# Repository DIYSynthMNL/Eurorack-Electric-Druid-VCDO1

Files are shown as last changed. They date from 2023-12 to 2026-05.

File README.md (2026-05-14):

This module is shared under a [Creative Commons Attribution-NonCommercial-ShareAlike 4.0 International license](https://creativecommons.org/licenses/by-nc-sa/4.0/). All credits go to Tom Wiltshire, founder of Electric Druid.

# Eurorack Electric Druid VCDO1

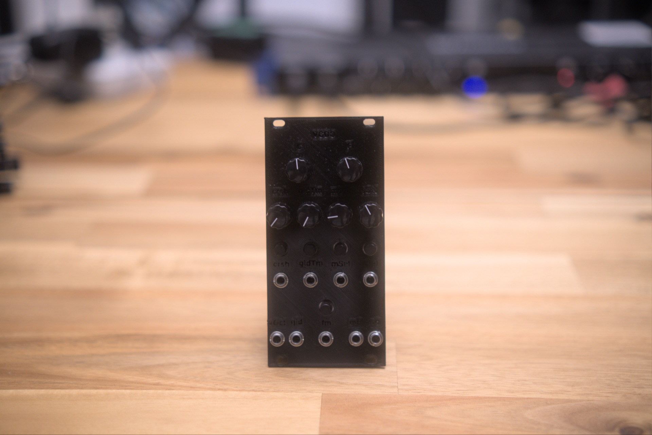
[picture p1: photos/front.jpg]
Electric Druid VCDO1 assembled


A Eurorack wavetable oscillator module built around the [VCDO1](https://electricdruid.net/product/vcdo-wavetable-oscillator/) chip from Electric Druid. The VCDO1 is a digital wavetable + sub-oscillator chip in an 18-pin DIP, running its own DAC internally and exposing both main and sub waveform outputs.

## Features

- **16 main waveforms** with smooth morphing via the Wave Select control
- **8 sub waveforms** with 4 selectable octave offsets (+1 oct, unison, −1 oct, −2 oct)
- **V/oct Note CV** input (0–5V, 5 octaves) with V/oct gain trim and offset trim
- **Exponential FM CV** input (±5V) with zero trim
- **Wave Select CV** for main and sub waveforms (±5V each)
- **Bitcrush** amount with both panel control and CV input
- **Glide (portamento)** time with both panel control and CV input, plus a separate Glide on/off gate input
- Two simultaneous outputs: Main oscillator and Sub oscillator (10Vpp each, anti-aliased)
- Eurorack ±12V power via either 16-pin IDC or 3-pin JST connector

The module adds **CV-controllable bitcrush and glide amounts** on top of the original Electric Druid VCDO datasheet circuit.

## Inputs and outputs

| Jack | Range | Notes |
|---|---|---|
| Note CV | 0–5V | 1V/oct, scaled to chip's 0–5V range; trim pots adjust V/oct and offset |
| FM CV | ±5V (10Vpp) | Inverted, scaled, offset-shifted to 0–5V; zero trim |
| Main Wave Select CV | ±5V (10Vpp) | Inverted, scaled, offset-shifted to 0–5V |
| Sub Wave Select CV | ±5V (10Vpp) | Inverted, scaled, offset-shifted to 0–5V |
| Bitcrush CV | ±5V (10Vpp) | Mixed with front-panel Bitcrush Control via Amount attenuator |
| Glide Time CV | ±5V (10Vpp) | Mixed with front-panel Glide Time Control via Amount attenuator |
| Glide on/off CV | 0–5V (gate) | NPN-buffered, drives chip's digital glide input |
| Main Out | 10Vpp | 4-pole Bessel reconstruction filter (≈18 kHz), buffered, 1K series |
| Sub Out | 10Vpp | Identical filter chain |

## Block diagram

```
                                  ┌───────────────────┐
  Note CV ─► [V/oct + offset] ──► │                   │
   FM CV ─► [scale + zero] ─────► │                   │ Main ─► [4-pole Bessel LP] ─► Main Out
  MainSel ─► [scale + offset] ──► │                   │
  SubSel ─► [scale + offset] ───► │   VCDO1 chip      │
 Bitcrush ─► [pot + CV+amount] ─► │   (digital        │
GlideTime ─► [pot + CV+amount] ─► │    wavetable      │
Glide on/off ─► [NPN inverter] ─► │    oscillator)    │ Sub  ─► [4-pole Bessel LP] ─► Sub Out
                                  │                   │
  Pots (Course, Fine,             │                   │
   MainSel, SubSel) ────────────► │                   │
                                  └───────────────────┘

  Eurorack ±12V ─► U6 (78M05) / U7 (79M05) ─► ±5V rails
```

## Power

- Eurorack ±12V in via **J3** (3-pin JST) or **J4** (16-pin IDC) — populate one
- Local U6 (78M05) generates +5V from +12V
- Local U7 (79M05) generates −5V from −12V
- R45 / R46 (10K) are optional minimum-load resistors

> **Note on the Electric Druid datasheet:** The original VCDO1 datasheet circuit has an error in the negative 5V regulator wiring. This schematic corrects it — verify when copying from the datasheet directly.

## Calibration

The board has three trim pots that need adjustment for accurate tracking. You'll need: a multimeter, a calibrated reference tone source (a tuner app, another tuned VCO, or a 1V/oct keyboard).

**RV1 — V/oct Adjust** sets the per-octave gain of the Note CV.
**RV2 — Offset trim** sets the DC offset of the Note CV (the "zero" pitch when 0V is applied).
**RV3 — FM Zero trim** ensures no DC drift on the FM input when nothing is patched.

Procedure:

1. **Warm up.** Power the module for at least 5 minutes — the temperature affects the chip and trim accuracy.
2. **Set baseline.** Freq Course and Fine at 12 o'clock. Nothing patched.
3. **Tune the base pitch.** Apply 0V to the Note CV jack (or short the jack tip to GND). Adjust **RV2 (Offset trim)** until the main output matches a known low reference (e.g., C2 = 65.41 Hz).
4. **Tune the per-octave gain.** Apply +4V to the Note CV jack. Adjust **RV1 (V/oct)** until the main output is exactly 4 octaves higher than step 3 (e.g., C6 = 1046.5 Hz).
5. **Iterate.** Step 3–4 interact slightly; bounce between them until both are accurate.
6. **Zero the FM input.** With Note CV at 0V and nothing patched into FM, adjust **RV3 (FM Zero trim)** until probing AIN_Freq_Mod_CV (or the FM jack tip) shows ~0V DC.

If tracking drifts at the extremes (very low or very high notes), check the timing capacitor area on the VCDO1 (this is a chip-internal characteristic).

## References

Local archived copies live in [`references/`](references/) so this repo stays useful if the upstream links die.

- **VCDO1 datasheet (Tom Wiltshire / Electric Druid, 2015)** — [local copy](references/VCDO1-Datasheet-ElectricDruid-2015.pdf) · [upstream](https://electricdruid.net/wp-content/uploads/2015/07/VCDO-Datasheet.pdf) — chip pinout, example circuit, and waveform reference. Note the negative-5V-regulator wiring error called out above; this schematic corrects it.
- [Electric Druid VCDO1 product page](https://electricdruid.net/product/vcdo-wavetable-oscillator/)

## Build status

What's ready for builders today, and what's still on the TODO list:

**Production assets** (what you need to actually fabricate and assemble a final unit)

- [x] Schematic — Rev 0.1.5 ([PDF](Schematic%20PDFs/Electric%20Druid%20VCDO1_Multiboard_Schematic_0.1.5.pdf))
- [ ] PCB layout — in progress — multiboard layout in `kicad/`, not yet separated for fab
- [ ] Gerber files for fabrication — none yet
- [x] BOM — [BOMs - VCDO1 - Schematic Rev 0.1.2.pdf](BOMs/BOMs%20-%20VCDO1%20-%20Schematic%20Rev%200.1.2.pdf)
- [ ] Final front panel (SVG/PDF for fab) — none yet
- [x] License — [LICENSE](LICENSE)

**Prototype assets** (for breadboard / perfboard / 3D-printed-panel builds before final PCB)

- [x] 3D-printed prototype panel STL — [VCDO.stl](3D%20printed%20front%20panel/VCDO.stl)

**Documentation**

- [x] Photos of the assembled module — see [photos/](photos/)
- [ ] Demo video — none yet
- [ ] Build / assembly instructions — none yet

Want to help fill a gap (build photos, gerbers, an assembly guide)? Open an issue or PR.

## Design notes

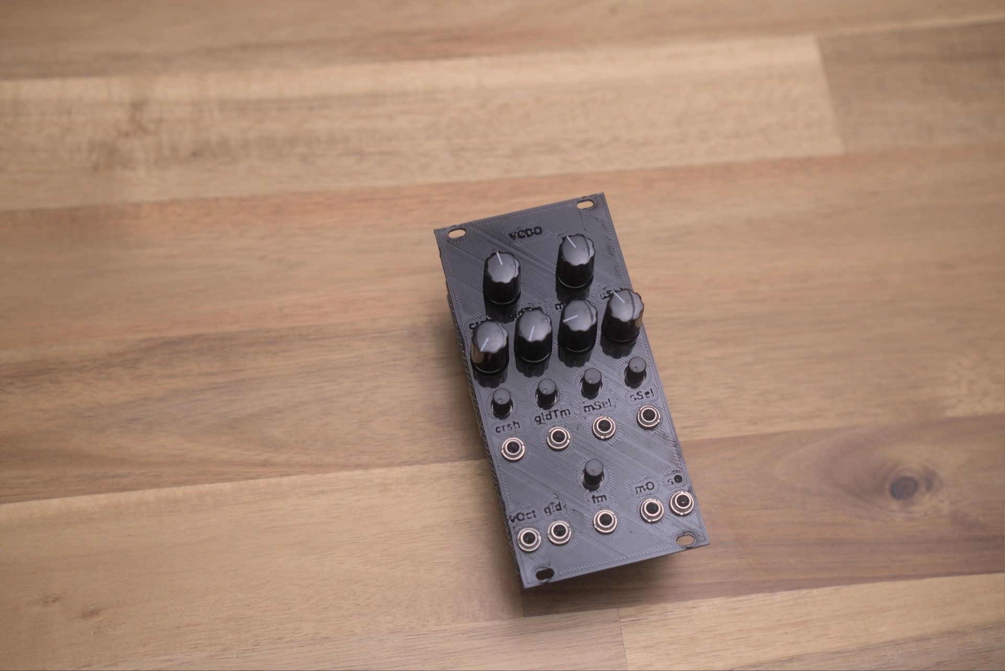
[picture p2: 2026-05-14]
photos/front-angle.jpg

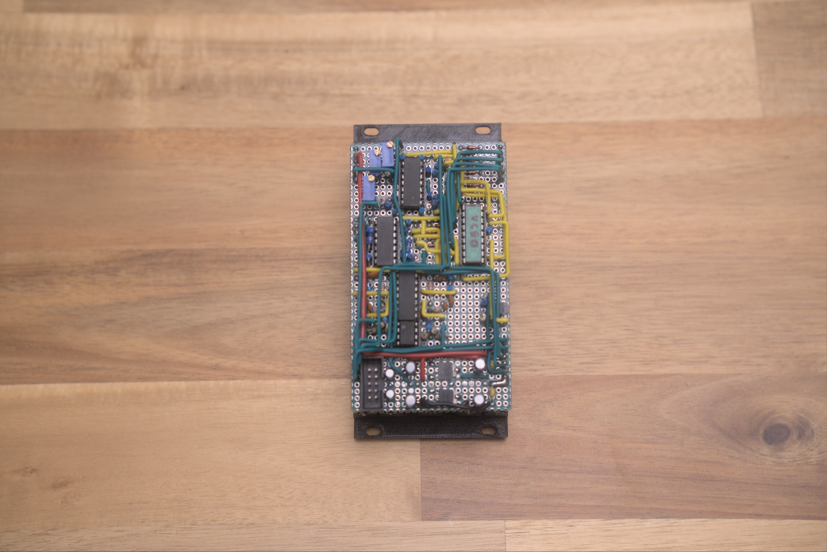
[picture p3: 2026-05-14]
photos/prototype-board-back.jpg

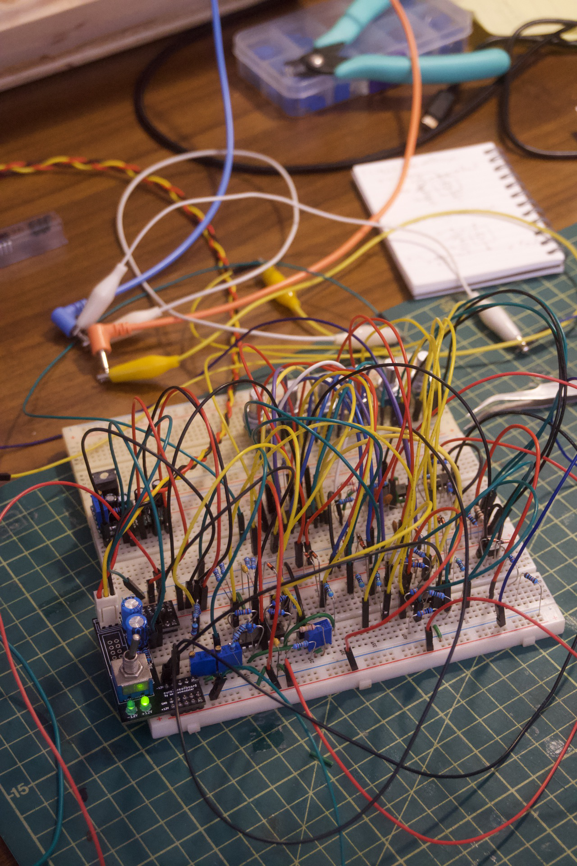
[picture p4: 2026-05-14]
photos/breadboarding/breadboard-2.jpg

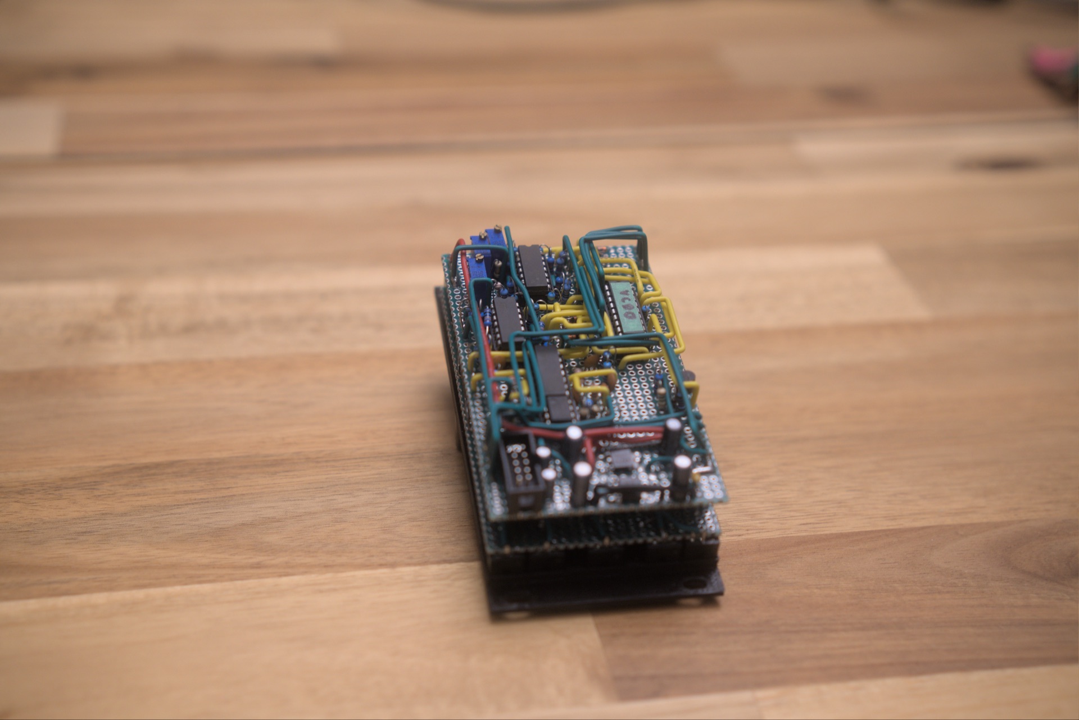
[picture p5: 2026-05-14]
photos/prototype-board.jpg

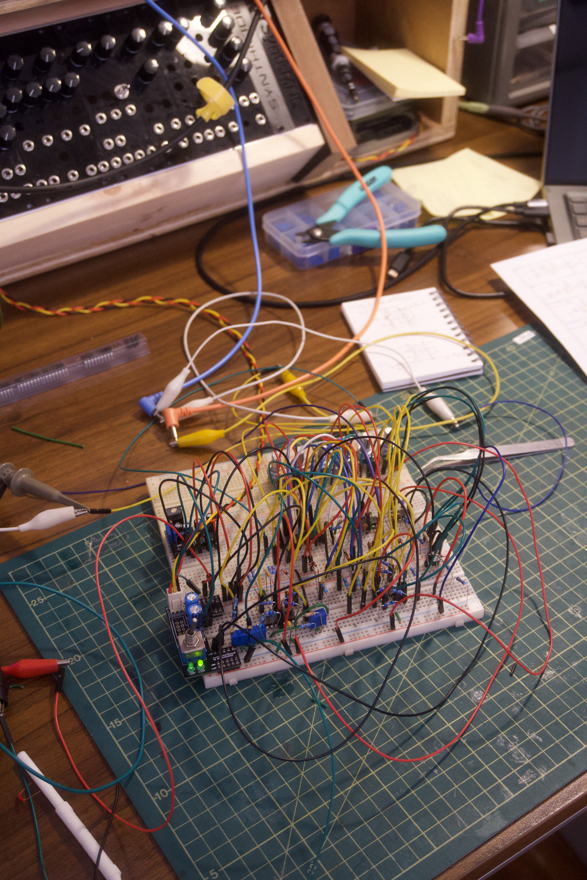
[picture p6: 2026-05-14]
photos/breadboarding/breadboard-1.jpg

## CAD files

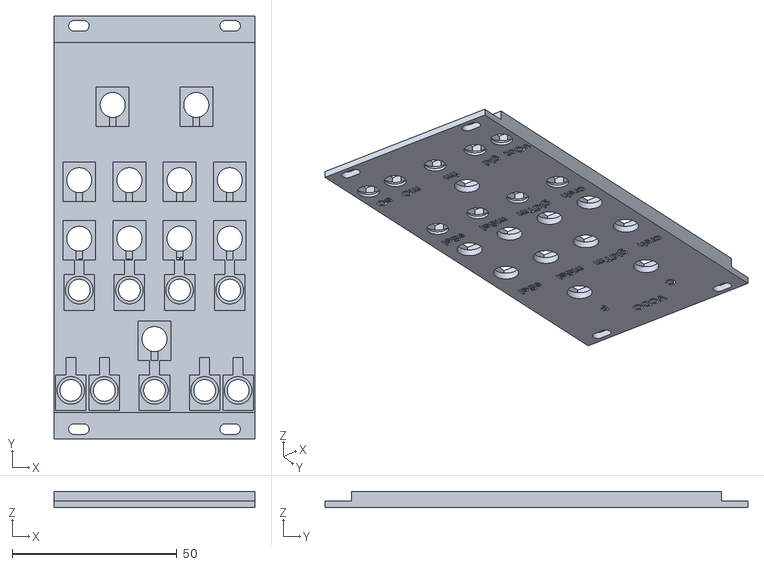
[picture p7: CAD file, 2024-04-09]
3D printed front panel/VCDO.stl
61.0 x 128.5 x 5.00

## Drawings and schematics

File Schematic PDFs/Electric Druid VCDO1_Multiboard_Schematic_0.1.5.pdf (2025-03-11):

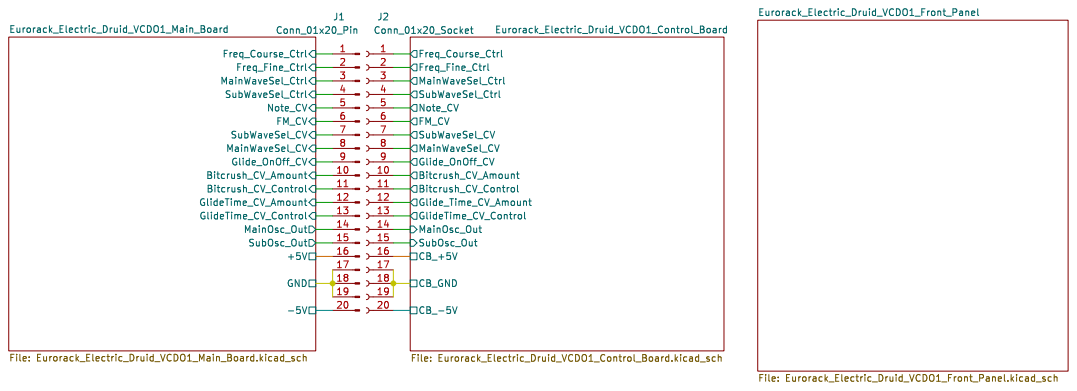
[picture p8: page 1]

Id: 1/4 Title: Eurorack Electric Druid VCDO1 - Control Board

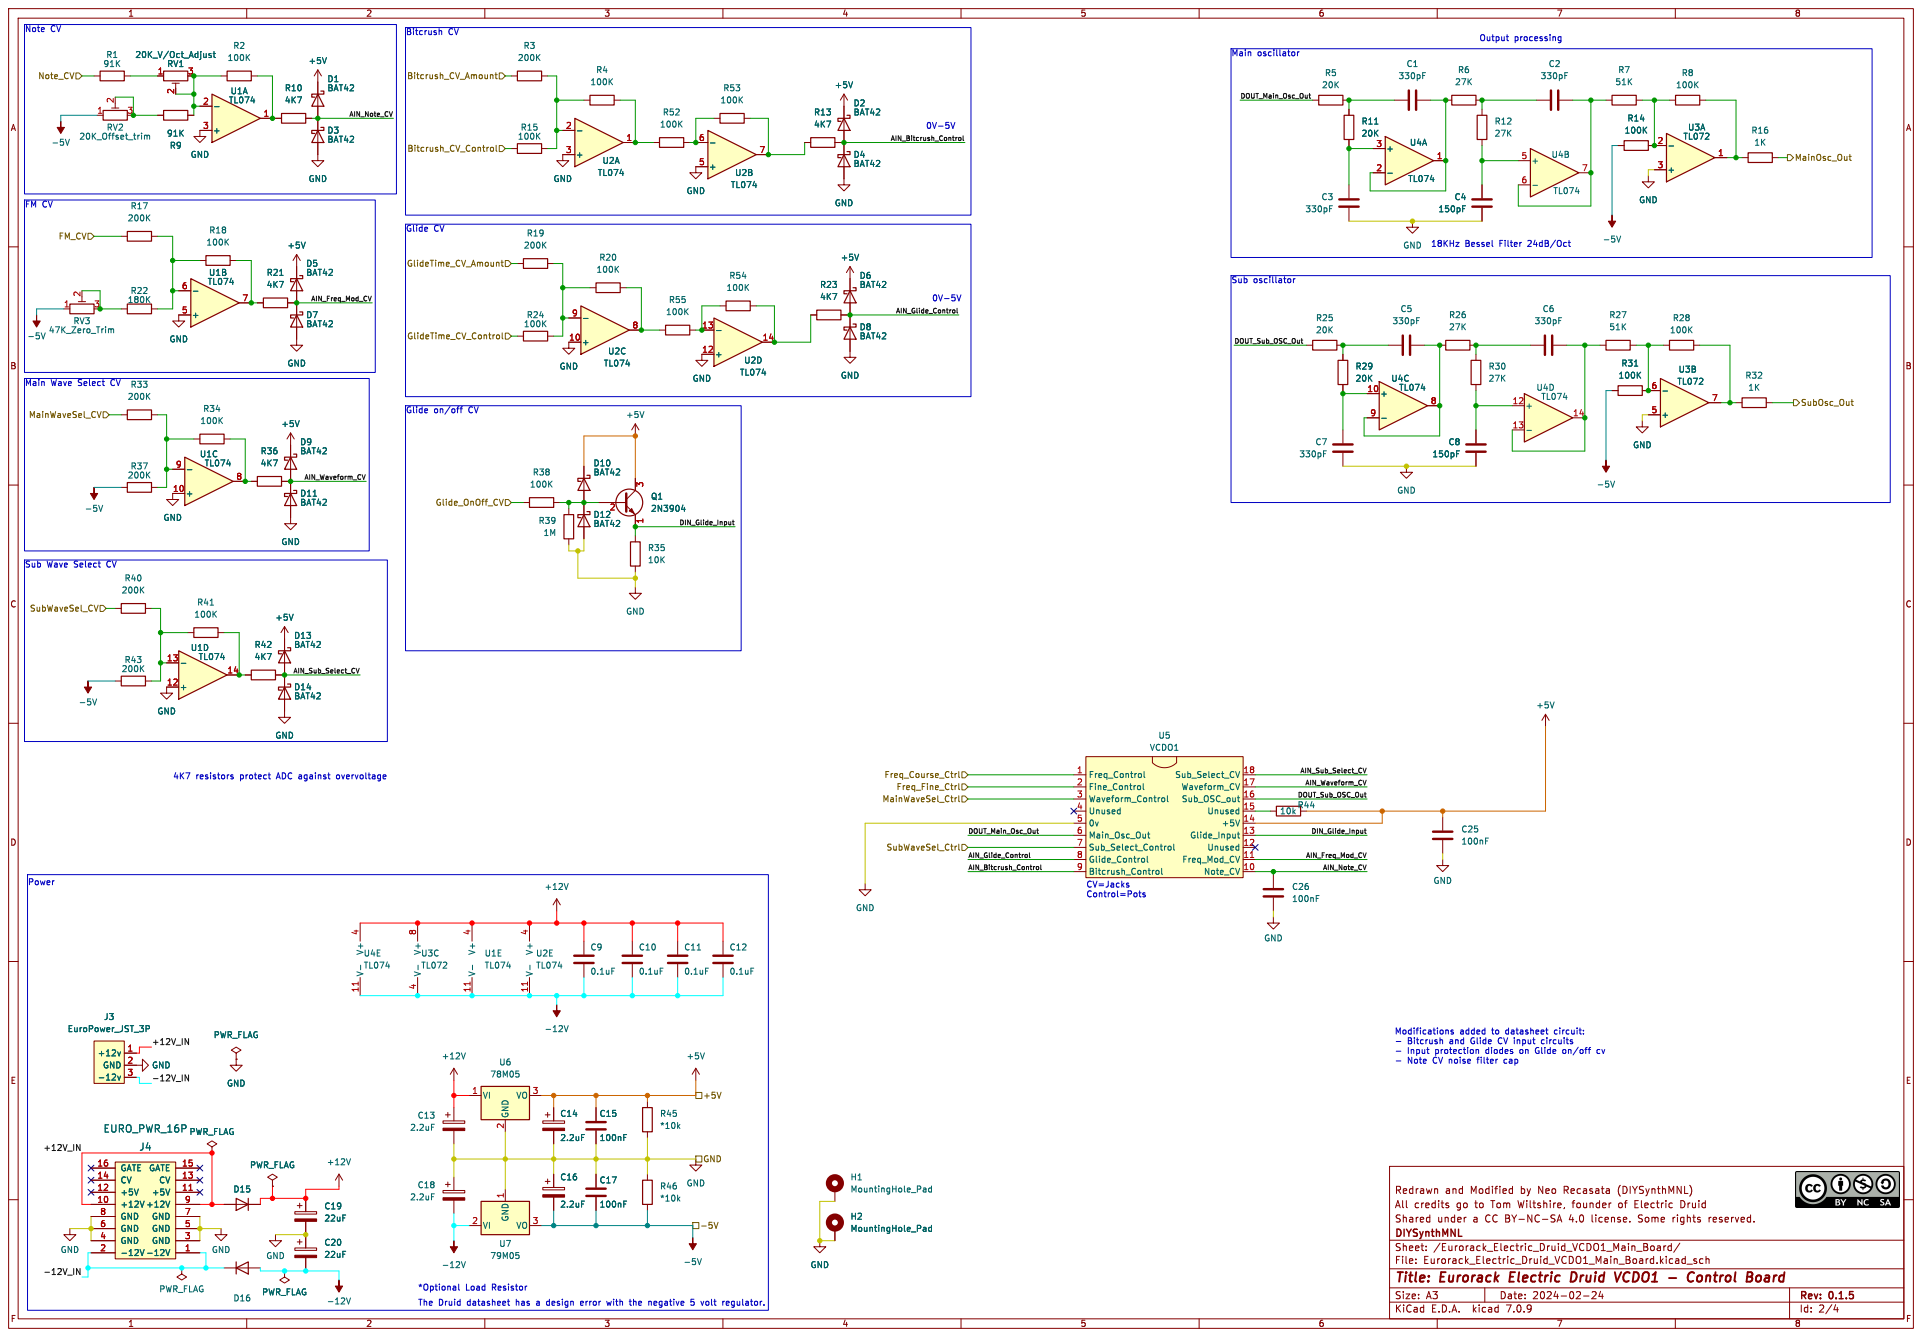
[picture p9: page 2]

Sub Wave Select CV

CV=Jacks Control=Pots

- Note CV noise filter cap

Id: 2/4 Title: Eurorack Electric Druid VCDO1 - Control Board

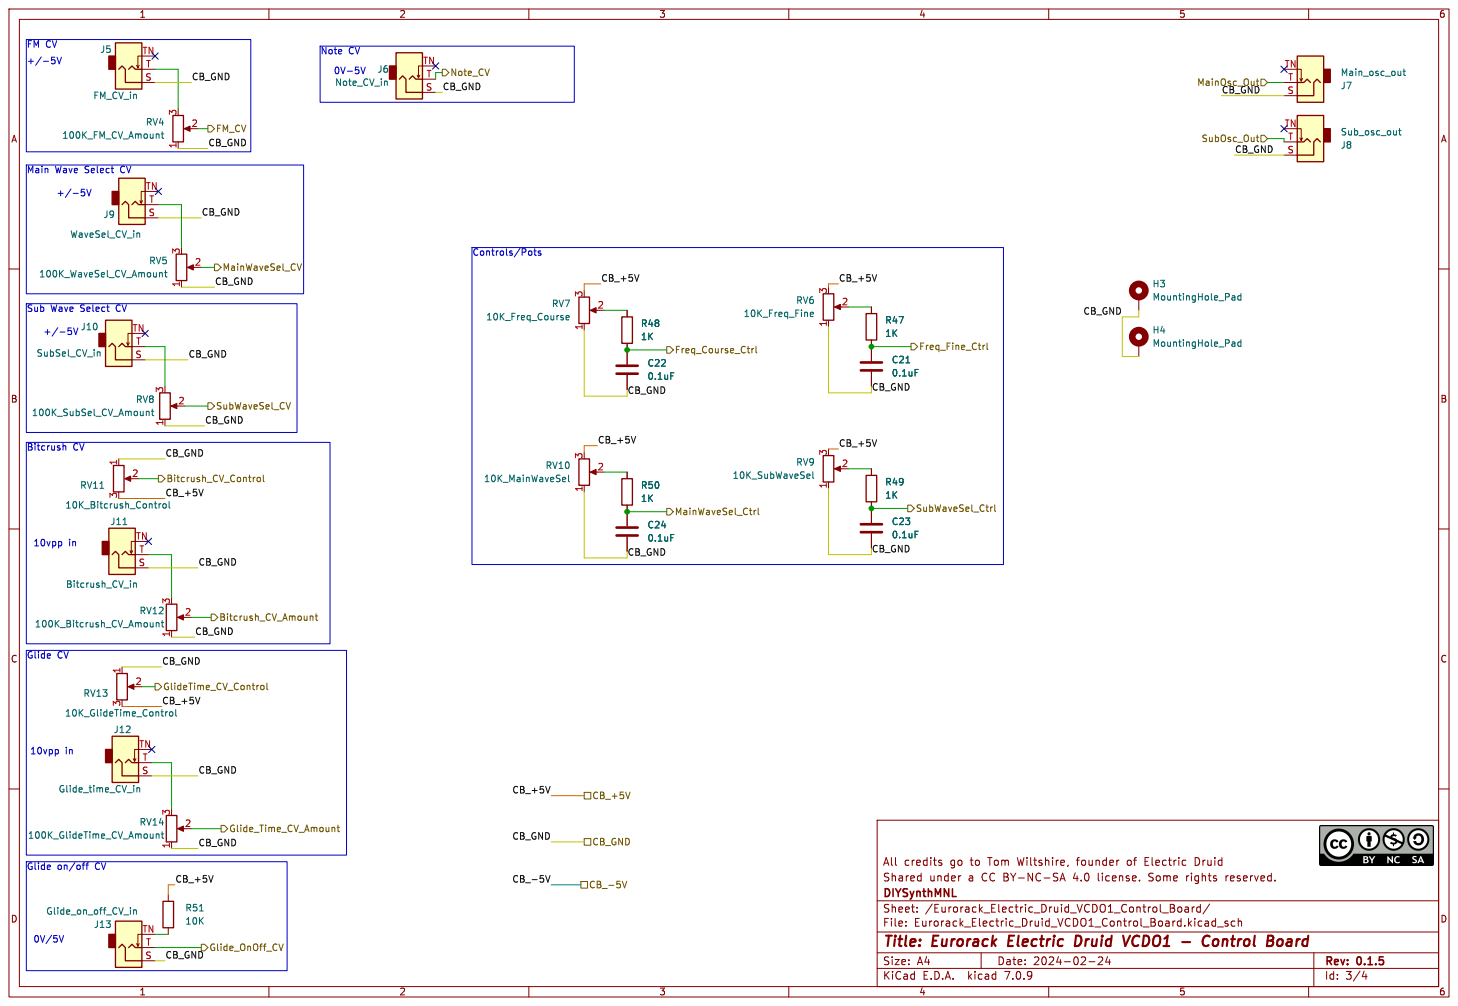
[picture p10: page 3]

Sub Wave Select CV

File: Eurorack_Electric_Druid_VCDO1_Control_Board.kicad_sch Sheet: /Eurorack_Electric_Druid_VCDO1_Control_Board/
Id: 3/4 Title: Eurorack Electric Druid VCDO1 - Control Board

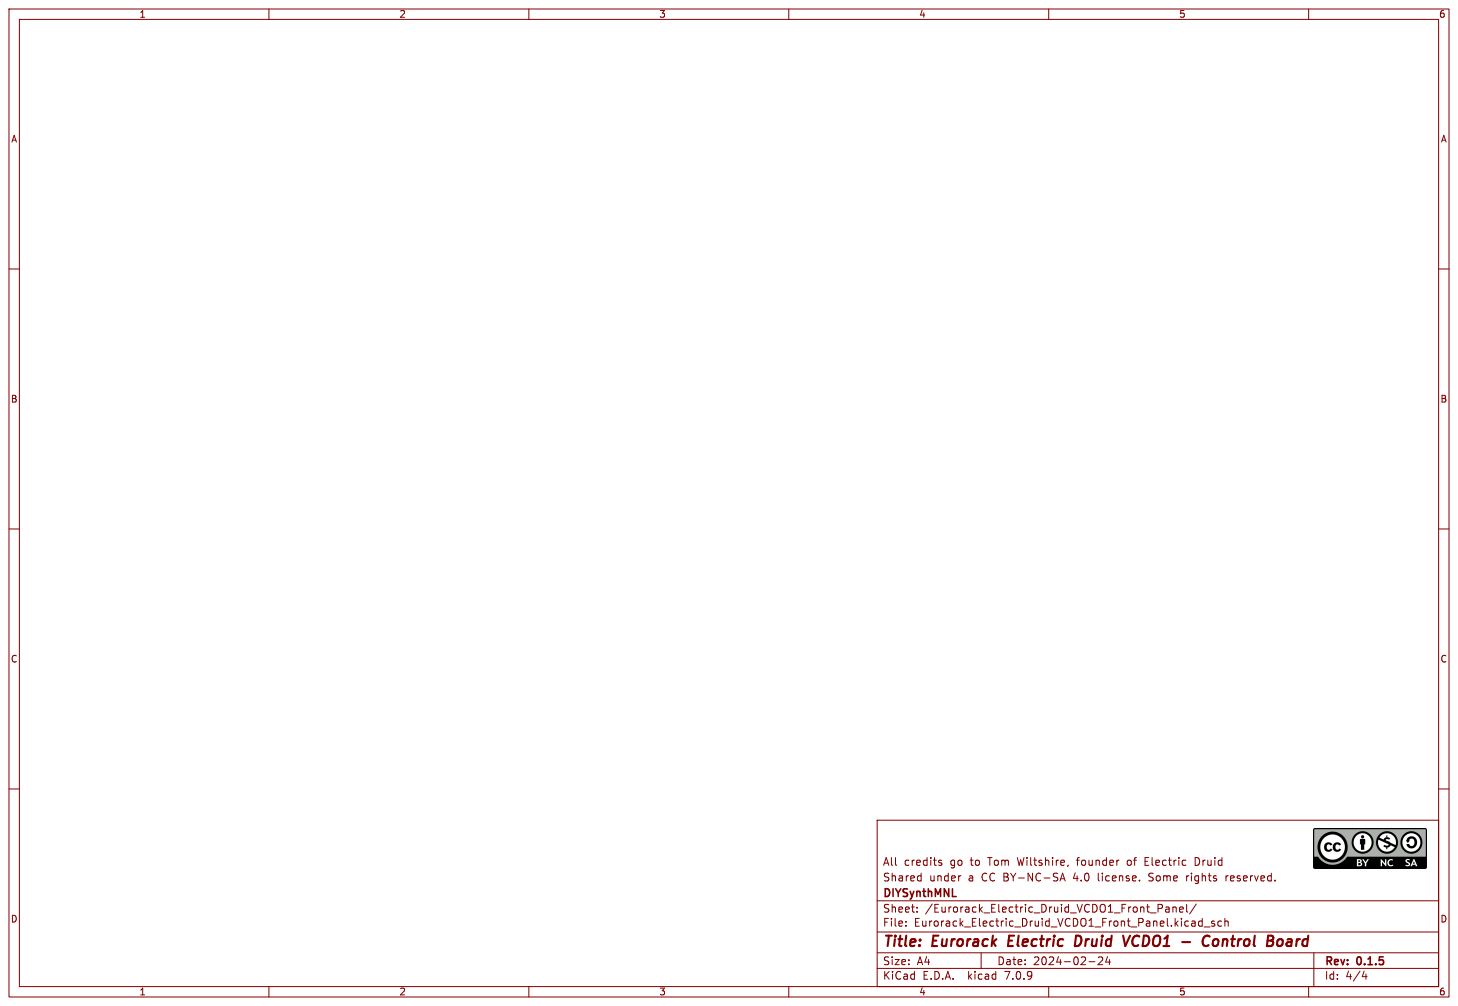
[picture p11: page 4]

File: Eurorack_Electric_Druid_VCDO1_Front_Panel.kicad_sch Sheet: /Eurorack_Electric_Druid_VCDO1_Front_Panel/
Id: 4/4 Title: Eurorack Electric Druid VCDO1 - Control Board

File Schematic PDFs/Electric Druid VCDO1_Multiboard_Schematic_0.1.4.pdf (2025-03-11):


Id: 1/4 Title: Eurorack Electric Druid VCDO1 - Control Board

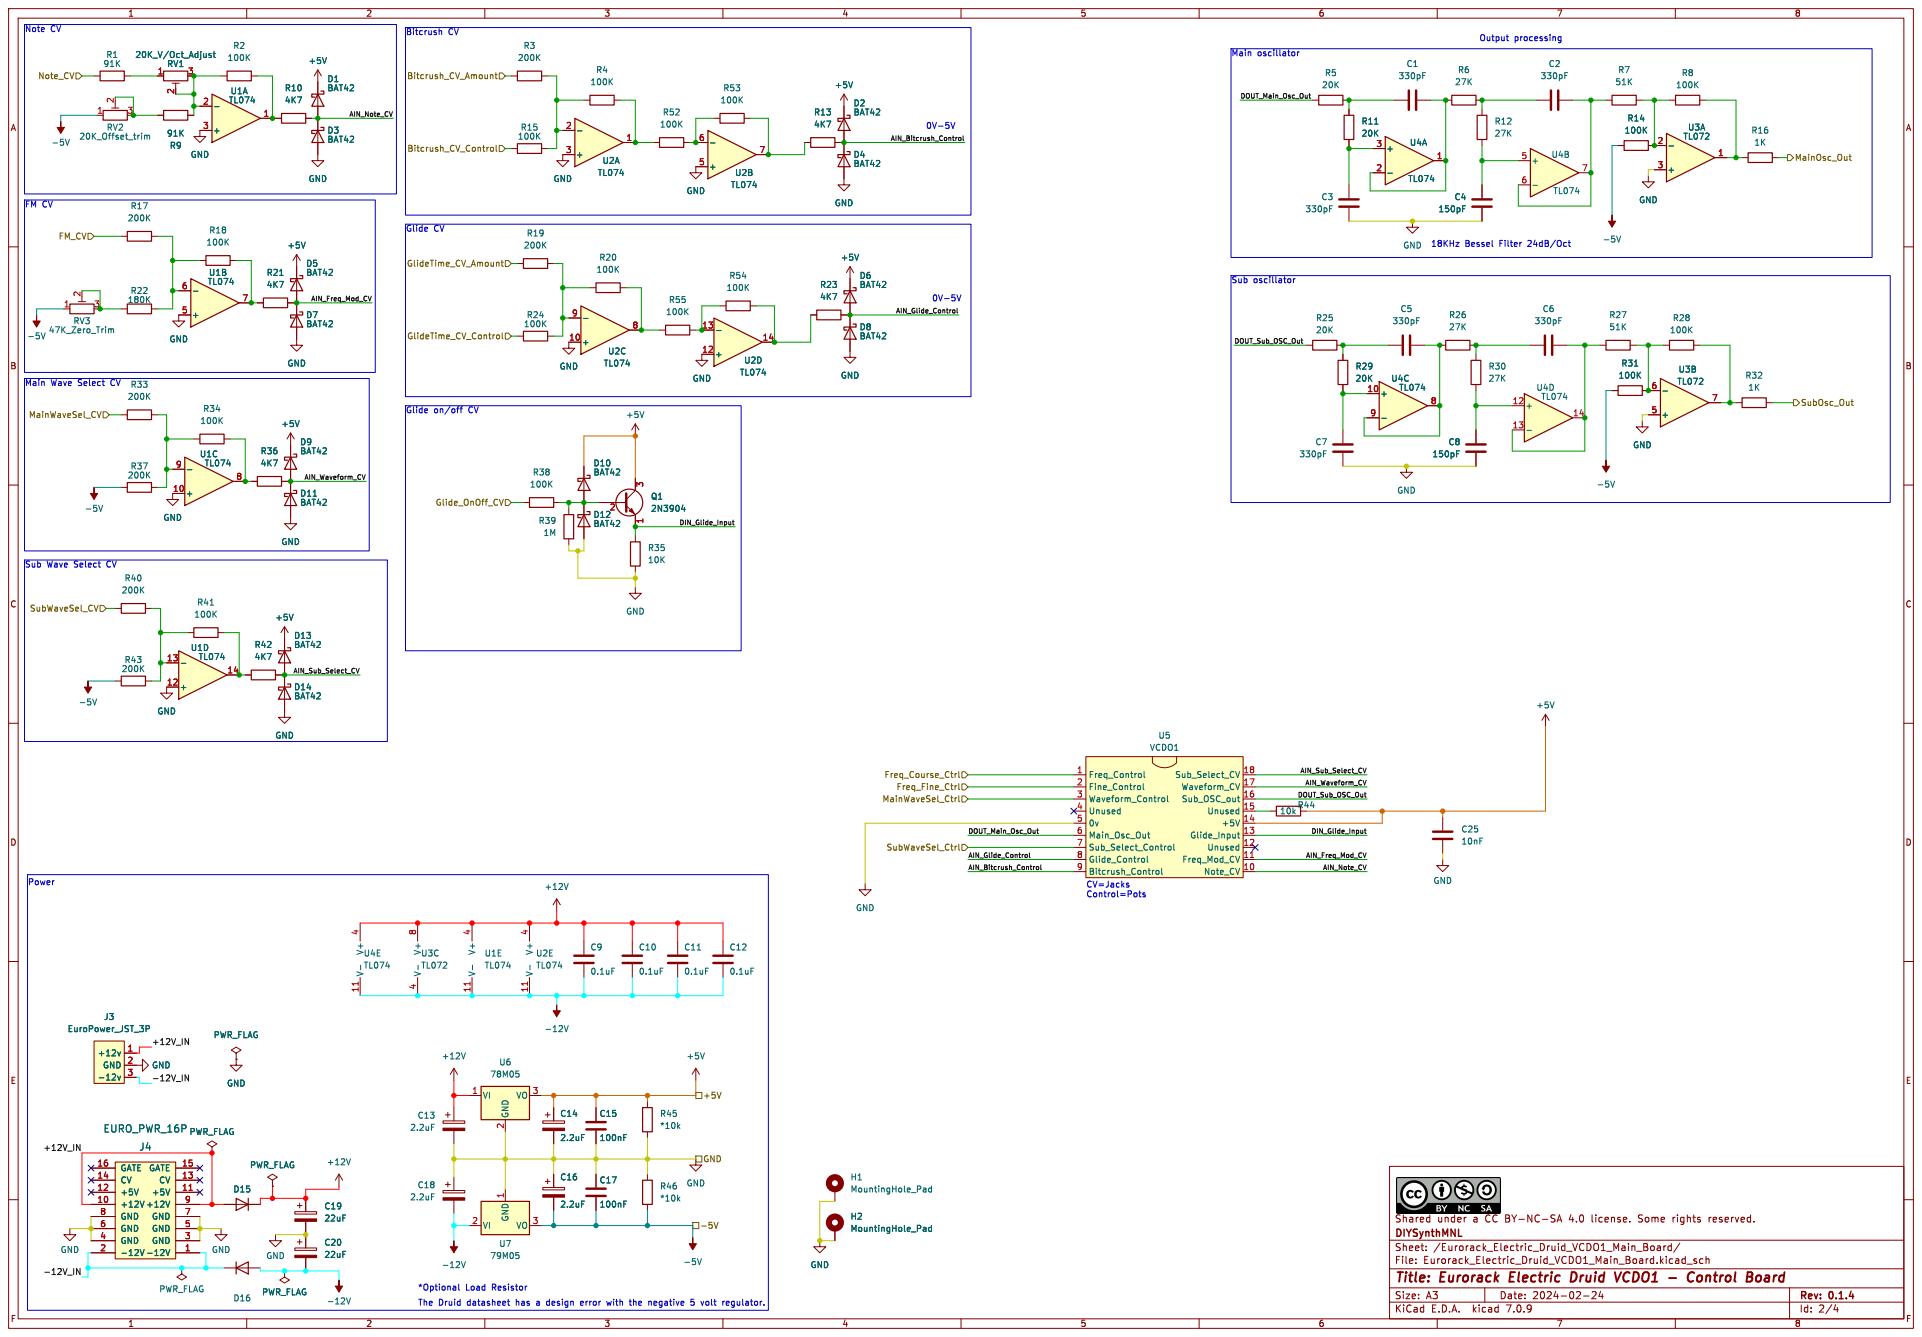
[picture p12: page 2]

18KHz Bessel Filter 24dB/Oct Output processing

Id: 2/4 Title: Eurorack Electric Druid VCDO1 - Control Board

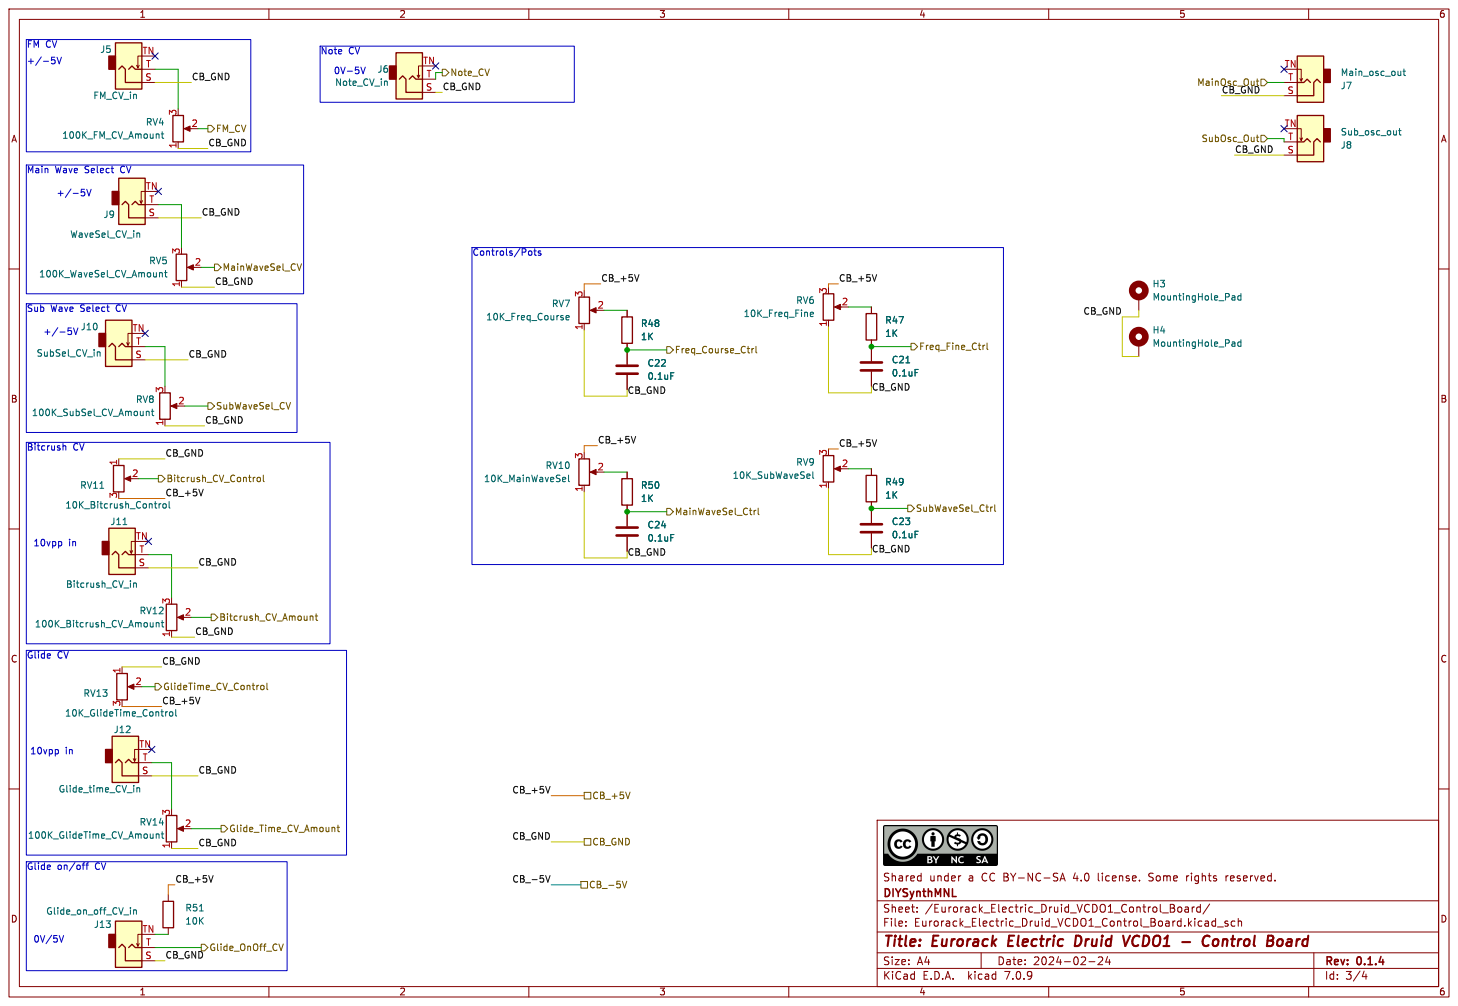
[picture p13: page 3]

Sub Wave Select CV

File: Eurorack_Electric_Druid_VCDO1_Control_Board.kicad_sch Sheet: /Eurorack_Electric_Druid_VCDO1_Control_Board/
Id: 3/4 Title: Eurorack Electric Druid VCDO1 - Control Board

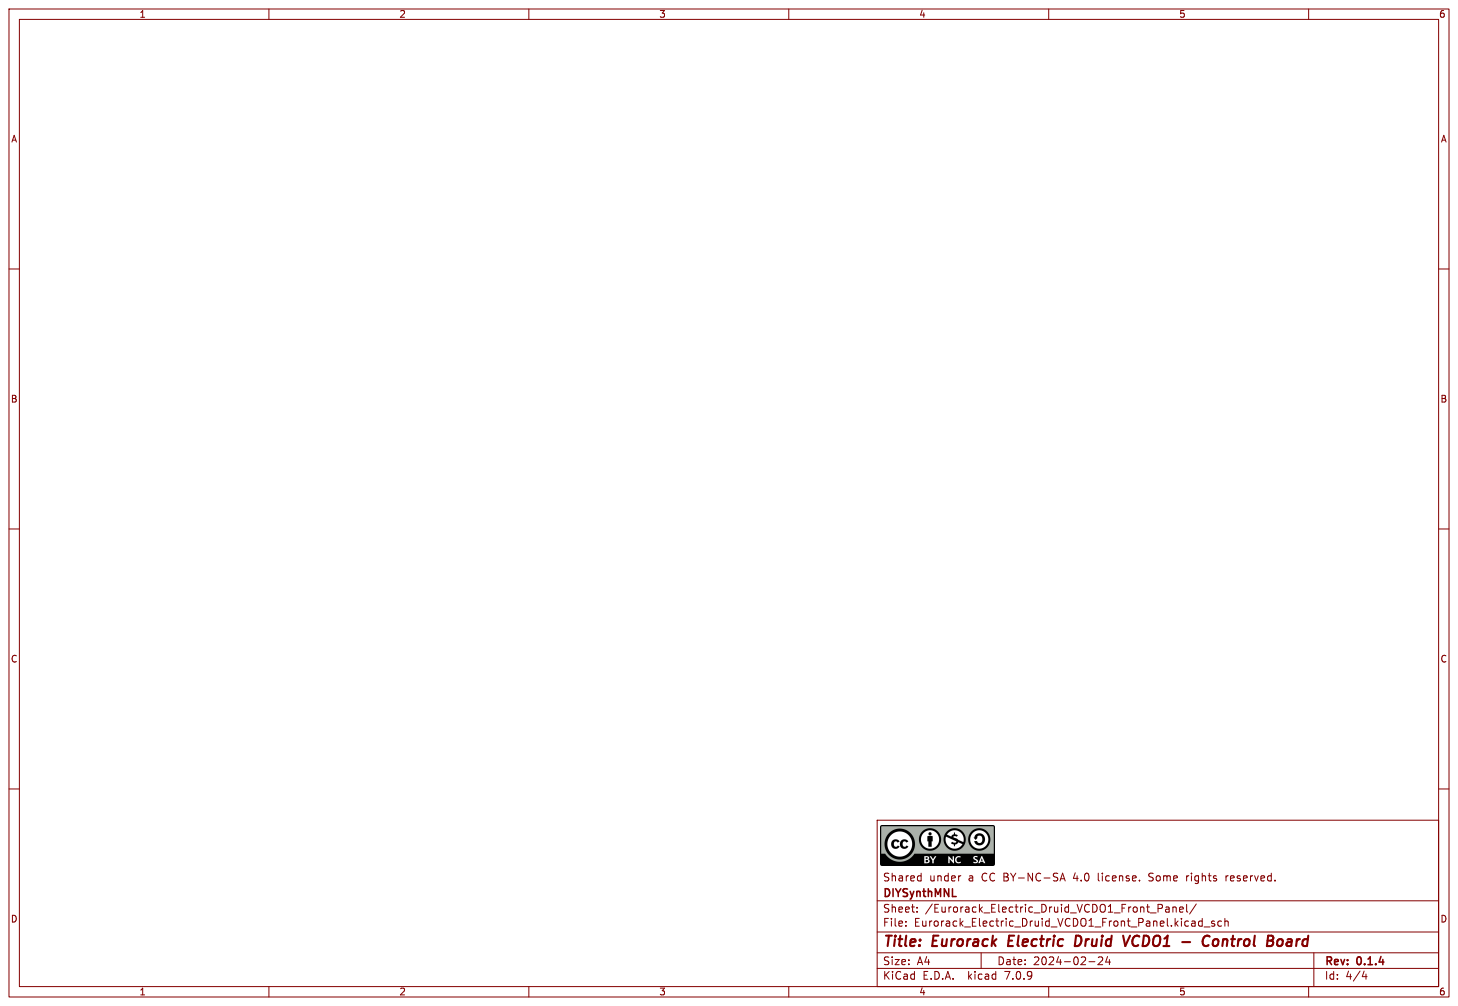
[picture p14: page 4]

File: Eurorack_Electric_Druid_VCDO1_Front_Panel.kicad_sch Sheet: /Eurorack_Electric_Druid_VCDO1_Front_Panel/
Id: 4/4 Title: Eurorack Electric Druid VCDO1 - Control Board

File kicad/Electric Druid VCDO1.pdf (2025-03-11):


Id: 1/4 Title: Eurorack Electric Druid VCDO1 - Control Board


Sub Wave Select CV

Id: 2/4 Title: Eurorack Electric Druid VCDO1 - Control Board


Sub Wave Select CV

File: Eurorack_Electric_Druid_VCDO1_Control_Board.kicad_sch Sheet: /Eurorack_Electric_Druid_VCDO1_Control_Board/
Id: 3/4 Title: Eurorack Electric Druid VCDO1 - Control Board


File: Eurorack_Electric_Druid_VCDO1_Front_Panel.kicad_sch Sheet: /Eurorack_Electric_Druid_VCDO1_Front_Panel/
Id: 4/4 Title: Eurorack Electric Druid VCDO1 - Control Board

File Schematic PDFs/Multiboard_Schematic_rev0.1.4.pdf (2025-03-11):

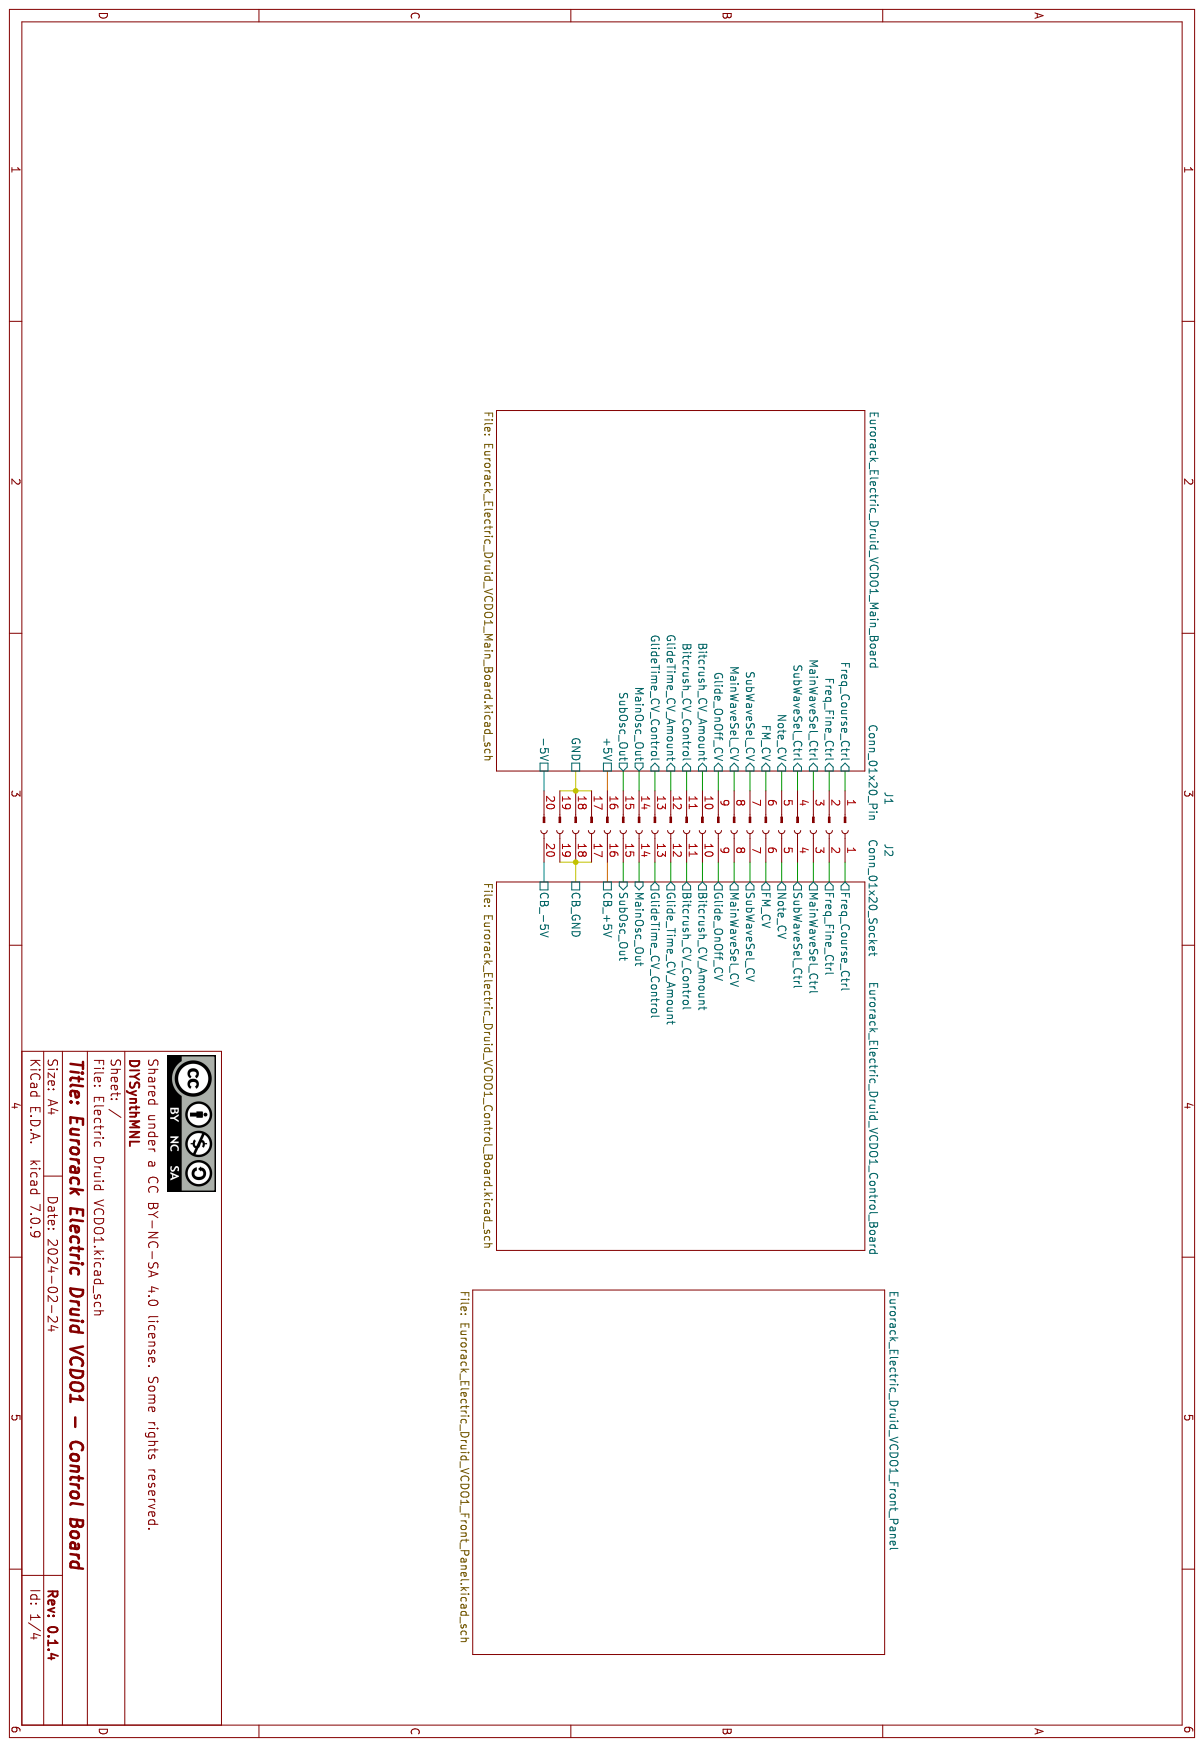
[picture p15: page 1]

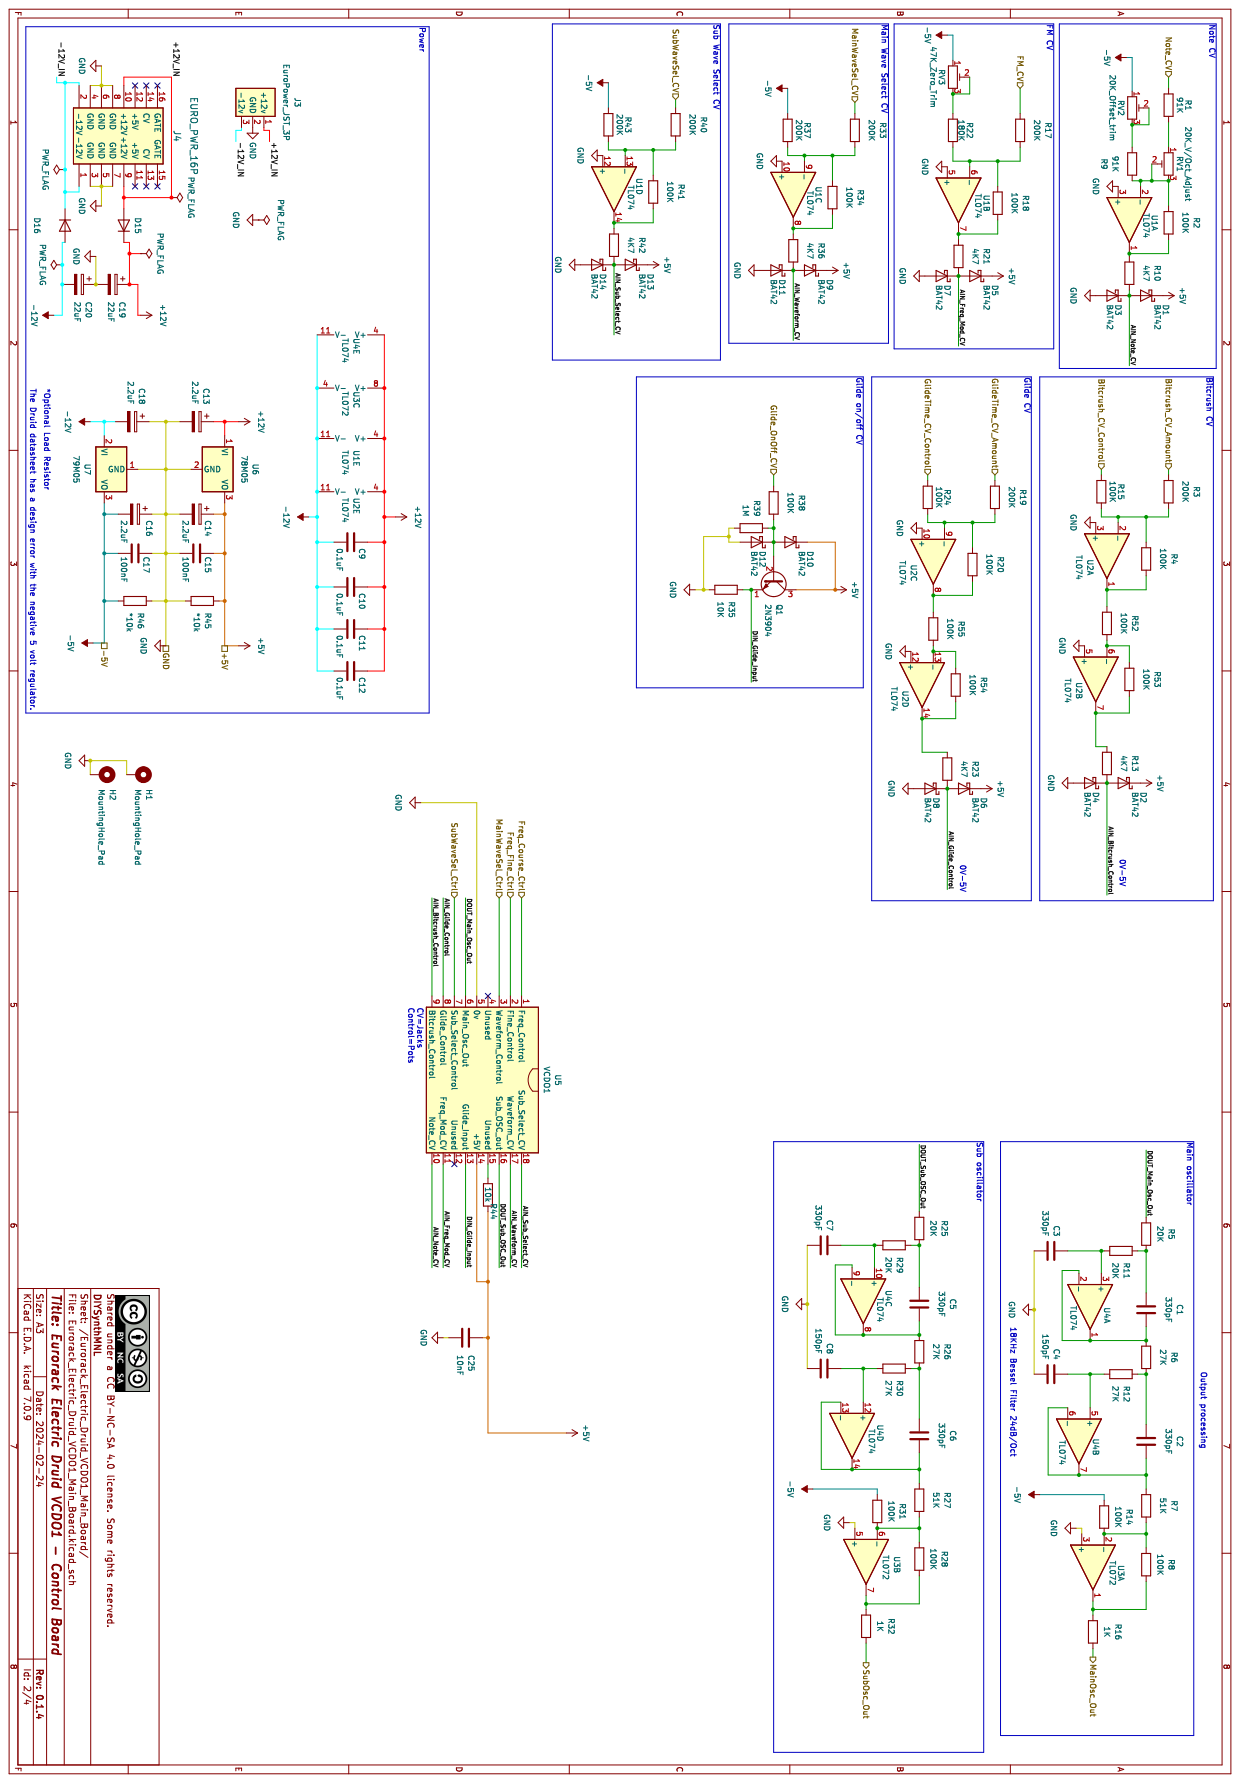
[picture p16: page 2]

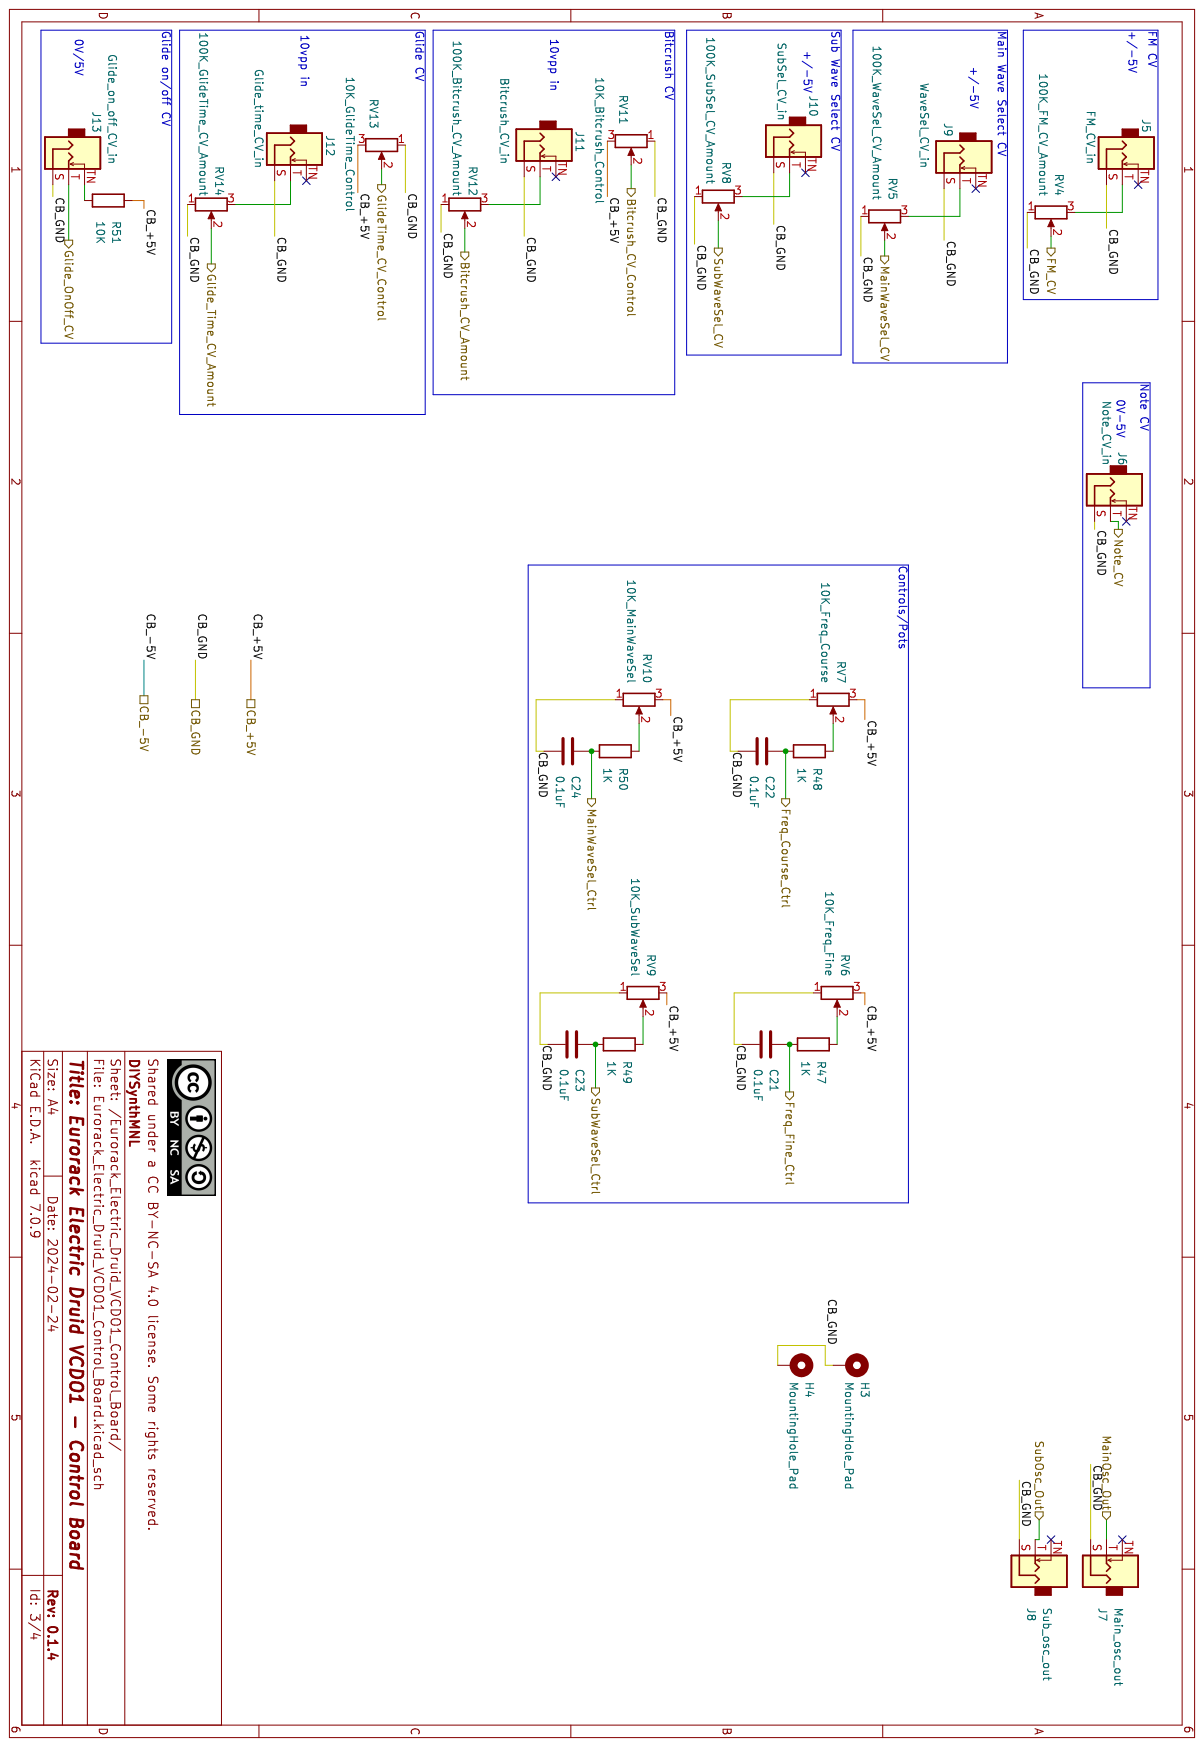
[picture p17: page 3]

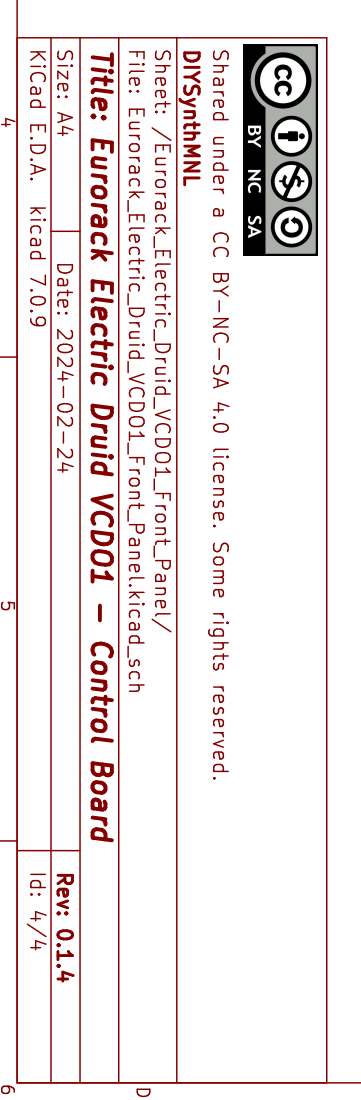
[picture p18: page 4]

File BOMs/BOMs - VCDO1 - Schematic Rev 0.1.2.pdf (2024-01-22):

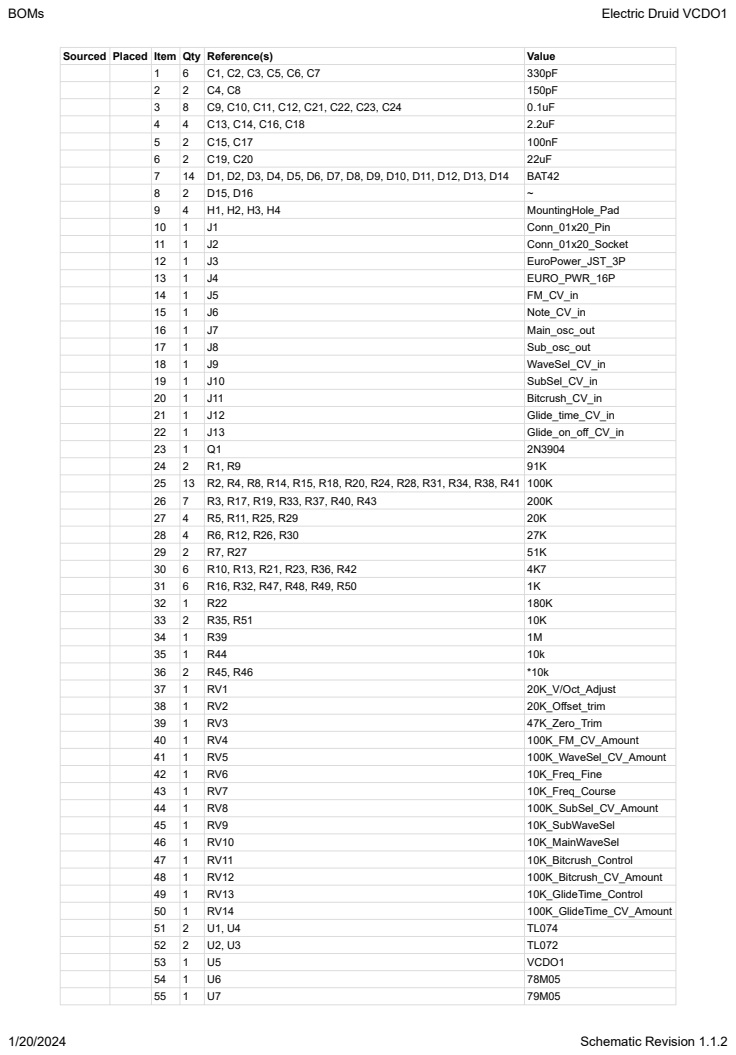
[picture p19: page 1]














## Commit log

2023-12-30 Initial commit
    Worked on starting the schematic
    [Electric Druid VCDO1.kicad_pcb, Electric Druid VCDO1.kicad_sch, Eurorack_Electric_Druid_VCDO1_Control_Board.kicad_sch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]
2023-12-30 Schematic rev0.1 update
    glide in, output filters done
    [Electric Druid VCDO1.kicad_sch]
2023-12-30 Root page filled with circuit
    [Electric Druid VCDO1.kicad_sch]
2023-12-31 added bitcrush and glide cv inputs
    [Electric Druid VCDO1.kicad_sch]
2023-12-31 Circuit rev0.1 finished
    I'll move on next to doing the different sheets for the multiboard workflow.
    [Electric Druid VCDO1.kicad_sch]
2024-01-06 Multiboard work update
    [Electric Druid VCDO1.kicad_sch, Eurorack_Electric_Druid_VCDO1_Control_Board.kicad_sch, Eurorack_Electric_Druid_VCDO1_Main_Board.kicad_sch]
2024-01-09 Schematic pdf update
2024-01-19 updated schematic to rev 0.1.1
    [Electric Druid VCDO1.kicad_sch, Eurorack_Electric_Druid_VCDO1_Control_Board.kicad_sch, Eurorack_Electric_Druid_VCDO1_Front_Panel.kicad_sch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]
2024-01-20 updated to schematic revision 1.2
    [Electric Druid VCDO1.kicad_sch, Eurorack_Electric_Druid_VCDO1_Control_Board.kicad_sch, Eurorack_Electric_Druid_VCDO1_Front_Panel.kicad_sch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]
2024-01-22 added schematic rev 0.1.2 bom
    [Electric Druid VCDO1.csv]
2024-01-22 added kicad gitignore
2024-01-27 cleaned up project directory
    [Electric Druid VCDO1.csv, Electric Druid VCDO1.kicad_pcb, Electric Druid VCDO1.kicad_sch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]
2024-03-09 updated schematic rev0.1.3
    [Electric Druid VCDO1.kicad_sch, Eurorack_Electric_Druid_VCDO1_Control_Board.kicad_sch, Eurorack_Electric_Druid_VCDO1_Front_Panel.kicad_sch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]
2025-03-11 Add 0.1.4 multiboard schematic
    [Electric Druid VCDO1.kicad_sch, Eurorack_Electric_Druid_VCDO1_Control_Board.kicad_sch, Eurorack_Electric_Druid_VCDO1_Front_Panel.kicad_sch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]
2025-03-11 Add schematic rev 0.1.5
    [Electric Druid VCDO1.kicad_sch, Eurorack_Electric_Druid_VCDO1_Control_Board.kicad_sch, Eurorack_Electric_Druid_VCDO1_Front_Panel.kicad_sch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]
2026-05-14 Fix Build status link path case
2026-05-14 Add photos/ placeholder for assembled-module shots
2026-05-14 Add assembled-module photos and update README hero
2026-05-14 Expand README with features table, block diagram, calibration procedure
